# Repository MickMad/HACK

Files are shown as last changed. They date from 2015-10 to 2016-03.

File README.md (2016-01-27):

#HACK
##HackAday Cortex Kit

A Cortex-M0+ development kit with an Atmel SAM R21, a USB device/host port, a regulator, some passives, a programming header, and breakout headers.

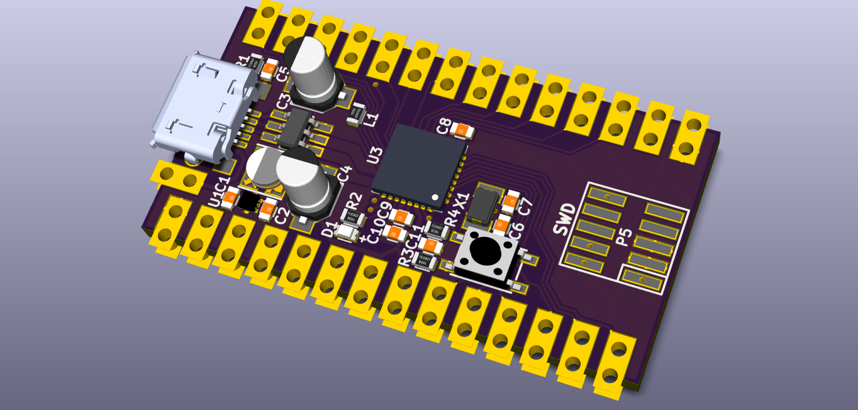
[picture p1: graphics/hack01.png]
HACK top


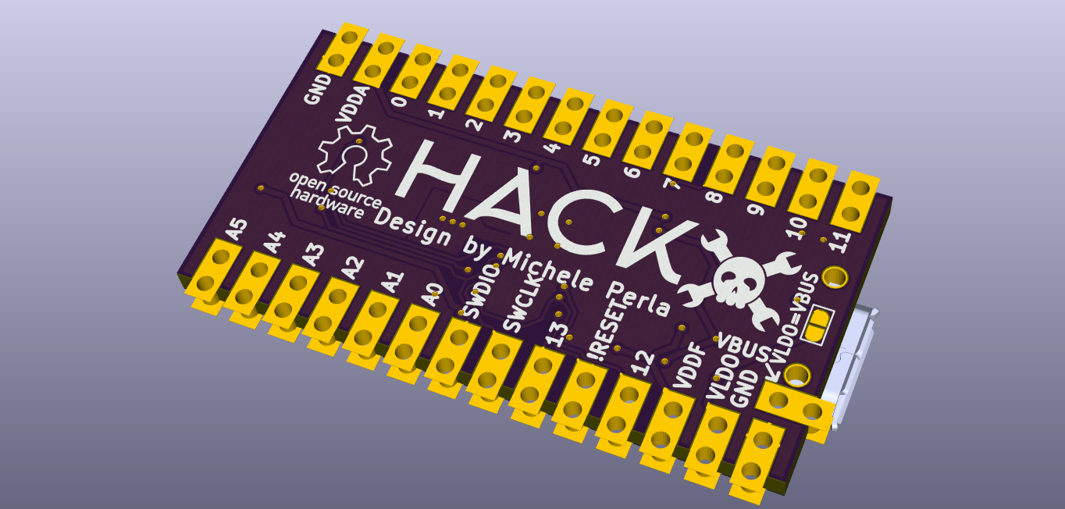
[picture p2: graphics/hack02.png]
HACK bottom


```
Copyright © Michele Perla 2015

This documentation describes Open Hardware and is licensed under the CERN OHL v. 1.2.
You may redistribute and modify this documentation under the terms of the CERN OHL v.1.2. 
(http://ohwr.org/cernohl). This documentation is distributed
WITHOUT ANY EXPRESS OR IMPLIED WARRANTY, INCLUDING OF
MERCHANTABILITY, SATISFACTORY QUALITY AND FITNESS FOR A
PARTICULAR PURPOSE. Please see the CERN OHL v.1.2 for applicable
conditions
```

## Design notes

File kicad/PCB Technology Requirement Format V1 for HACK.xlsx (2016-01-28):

深圳矽递科技有限公司Seeed Technology Inc.
PCB Technology Requirement Format
PCB Name & Version | HACK, rev 1
PCB Material PCB板材： | (Rigid)FR－4
PCB Size PCB大小： | inch | (1.4500) × (0.7500)
PCB Layer PCB层数： | 2
Thickness PCB厚度：
 |  | 1.6mm
Copper Weight铜厚： | 1oz
PCB Colour阻焊颜色： |  | Black黑色
Silkscreen字符颜色： |  | White白色
Pads Finished焊盘喷镀： | (Hasl-lead free)无铅喷锡
Via solder mask阻焊覆盖： |  | solder mask opening过孔开窗
Minimum trace/space (mm)最小线宽 | 0.178mm | Minimum hole size (mm)最小孔径 | 0.508mm
Special requirements特殊工艺： | YES | (Put requirements here)
Comment: | Do not solder Header Pins (add as kit)

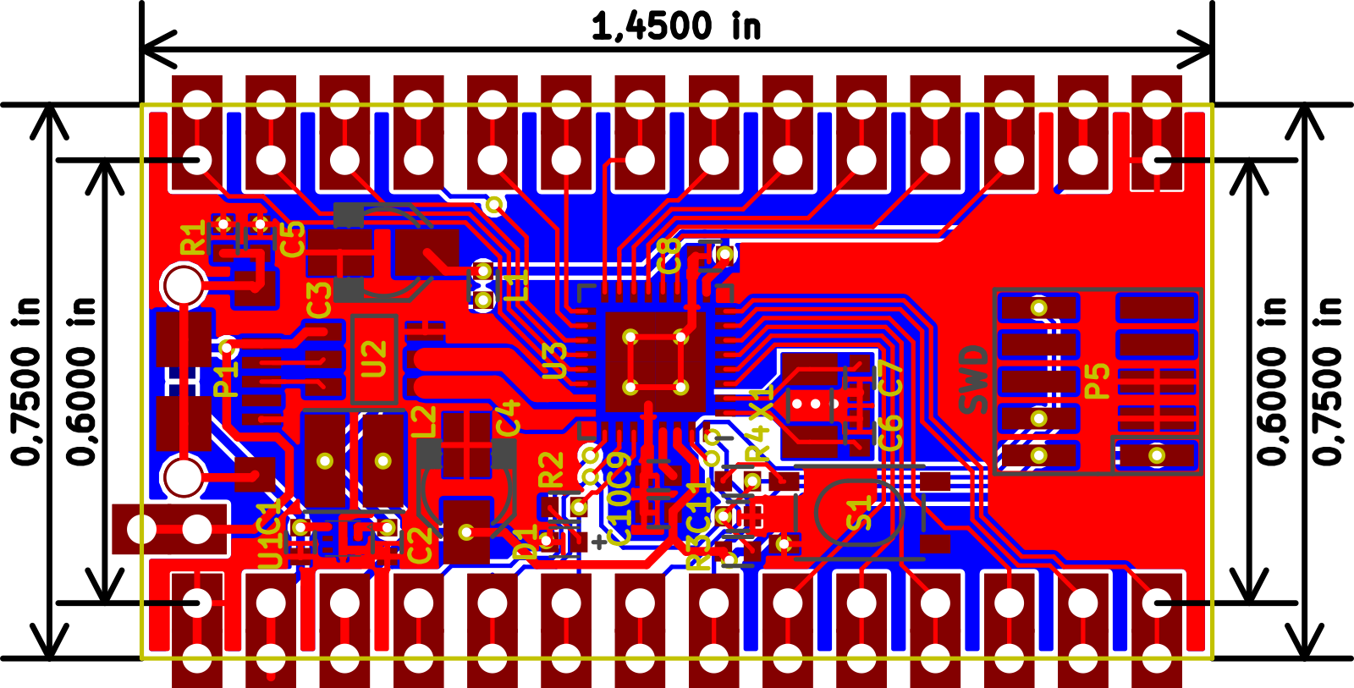
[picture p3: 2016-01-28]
graphics/hack-brd.png

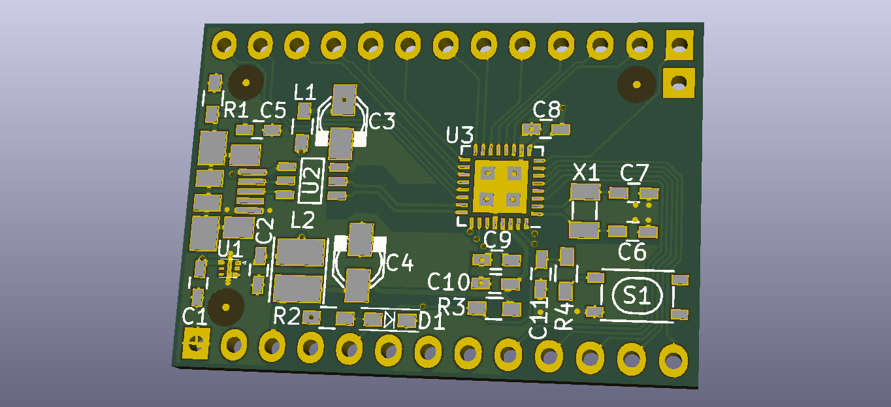
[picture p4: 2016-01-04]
graphics/hack - 3D top.png

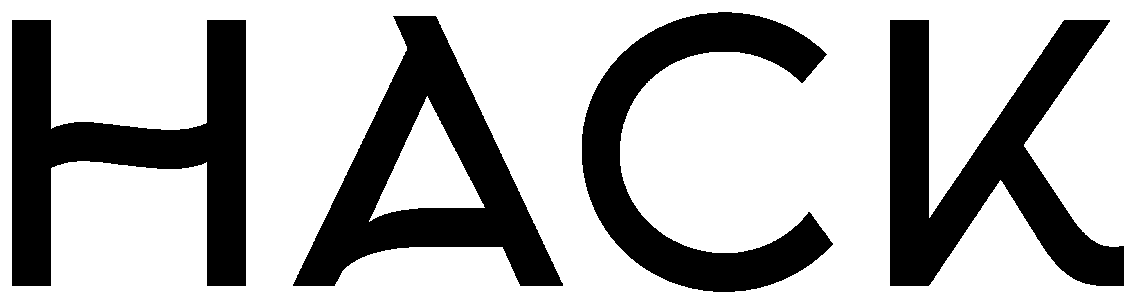
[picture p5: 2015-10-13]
graphics/hack.bmp

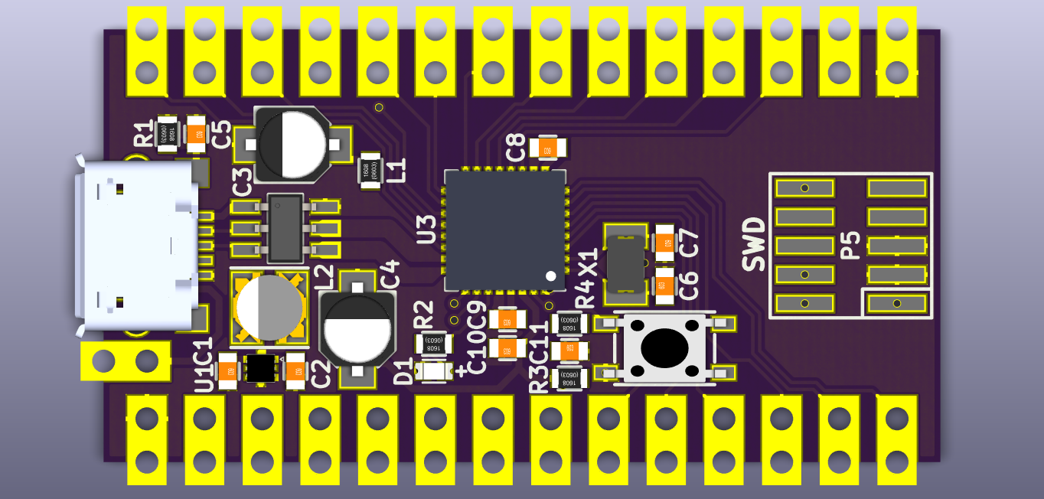
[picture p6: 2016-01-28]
graphics/hack03.png

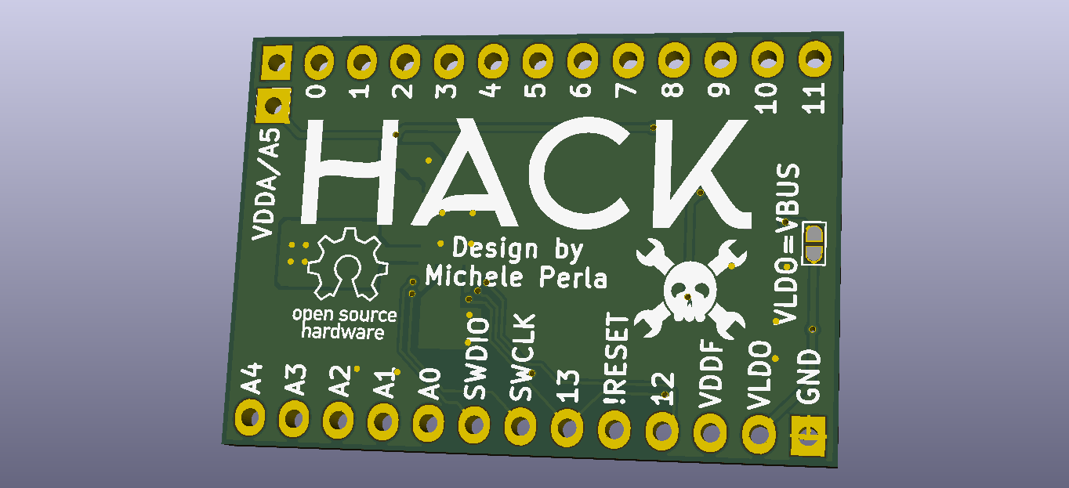
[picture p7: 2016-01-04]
graphics/hack - 3D bottom.png

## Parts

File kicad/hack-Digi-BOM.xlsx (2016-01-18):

 |  |  |  |  |  |  | Board Qty: | 21
 |  |  |  |  |  |  | Total Cost: | $171.97 |  |  |  | $182.13 |  |  |  |  |  | $195.82 |  |  |  |  |  | $137.80
 |  |  |  |  |  |  | Unit Cost: | $8.19
Global Part Info |  |  |  |  |  |  |  |  | Digi-Key |  |  |  |  |  | Mouser |  |  |  |  |  | Newark
Refs | Value | Desc | Footprint | Manf | Manf# | Qty | Unit$ | Ext$ | Avail | Purch | Unit$ | Ext$ | Cat# | Doc | Avail | Purch | Unit$ | Ext$ | Cat# | Doc | Avail | Purch | Unit$ | Ext$ | Cat# | Doc
C3,C4 | 10uF |  | hack-footprints:c_elec_3x5.3 |  | UWX1C100MCL2GB | 42 | $0.13 | $5.63 | 146304 |  | $0.16 | $6.84 | 493-2099-1-ND | Link (http://www.digikey.com/product-detail/en/UWX1C100MCL2GB/493-2099-1-ND/590074) | 22886 |  | $0.13 | $5.63 | 647-UWX1C100MCL2 | Link (http://www.mouser.com/Search/Refine.aspx?Keyword=UWX1C100MCL2GB) | 829 |  | $0.20 | $8.19 | 58R3619 | Link (http://www.newark.com/nichicon/uwx1c100mcl2gb/aluminum-electrolytic-capacitor/dp/58R3619)
D1 | RED |  | hack-footprints:LED_0603_HandSoldering |  | LTST-C190KRKT | 21 | $0.19 | $3.91 | 294147 |  | $0.19 | $3.91 | 160-1436-1-ND | Link (http://www.digikey.com/product-detail/en/LTST-C190KRKT/160-1436-1-ND/386816) | 47288 |  | $0.23 | $4.87 | 859-LTST-C190KRKT | Link (http://www.mouser.com/Search/Refine.aspx?Keyword=LTST-C190KRKT) | 1769 |  | $0.43 | $9.11 | 09J9435 | Link (http://www.newark.com/lumex/sml-lx0603siw-tr/led-red-0-8mm-x-1mm-60mcd-636nm/dp/09J9435)
U2 | STF202 |  | hack-footprints:TSOP-6 |  | STF202-22T1G | 21 | $0.49 | $10.33 | 10793 |  | $0.57 | $11.95 | STF202-22T1GOSCT-ND | Link (http://www.digikey.com/product-detail/en/STF202-22T1G/STF202-22T1GOSCT-ND/720944) | 12154 |  | $0.49 | $10.33 | 863-STF202-22T1G | Link (http://www.mouser.com/Search/Refine.aspx?Keyword=STF202-22T1G) | 7927 |  | $0.66 | $13.86 | 45J2271 | Link (http://www.newark.com/on-semiconductor/stf202-22t1g/rc-n-w-filter-22-ohm-68pf-tsop/dp/45J2271)
C5 | 4.7nF |  | hack-footprints:C_0603_HandSoldering |  | CC0603KRX7R9BB472 | 21 | $0.02 | $0.40 | 45511 |  | $0.03 | $0.55 | 311-1083-1-ND | Link (http://www.digikey.com/product-detail/en/CC0603KRX7R9BB472/311-1083-1-ND/302993) | 48553 |  | $0.02 | $0.40 | 603-C0603KRX7R9BB472 | Link (http://www.mouser.com/Search/Refine.aspx?Keyword=CC0603KRX7R9BB472) | 2940 |  | $0.05 | $0.97 | 68R4808 | Link (http://www.newark.com/yageo/cc0603krx7r9bb472/ceramic-capacitor-4700pf-50v-x7r/dp/68R4808)
L2 | 10uH |  | hack-footprints:ELLVFG |  | ELL-VFG100MC | 21 | $0.21 | $4.45 | 526 |  | $0.51 | $10.71 | PCD2293CT-ND | Link (http://www.digikey.com/product-detail/en/ELL-VFG100MC/PCD2293CT-ND/1938502) | 1767 |  | $0.47 | $9.91 | 667-ELL-VFG100MC | Link (http://www.mouser.com/Search/Refine.aspx?Keyword=ELL-VFG100MC) | 0 |  | $0.21 | $4.45 | 15R1033 | Link (http://www.newark.com/webapp/wcs/stores/servlet/Search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)
U3 | ATSAMD21E |  | hack-footprints:QFN-32-1EP_5x5mm_Pitch0.5mm |  | ATSAMD21E18A-MU | 21 | $3.04 | $63.84 | 907 |  | $4.49 | $94.35 | ATSAMD21E18A-MU-ND | Link (http://www.digikey.com/product-detail/en/ATSAMD21E18A-MU/ATSAMD21E18A-MU-ND/4935887) | 328 |  | $4.43 | $93.03 | 556-ATSAMD21E18A-MU | Link (http://www.mouser.com/ProductDetail/Atmel/ATSAMD21E18A-MU/) | 0 |  | $3.04 | $63.84 | 45X9914 | Link (http://www.newark.com/atmel/atsamd21e18a-mu/cortex-m0-64kb-flash-8kb-sram/dp/45X9914)
L1 | BLM18EG221 |  | hack-footprints:L_0603_HandSoldering |  | BLM18EG221SN1D | 21 | $0.10 | $2.12 | 309192 |  | $0.17 | $3.67 | 490-3992-1-ND | Link (http://www.digikey.com/product-detail/en/BLM18EG221SN1D/490-3992-1-ND/1016252) | 80667 |  | $0.12 | $2.60 | 81-BLM18EG221SN1D | Link (http://www.mouser.com/Search/Refine.aspx?Keyword=BLM18EG221SN1D) | 13079 |  | $0.10 | $2.12 | 73M9090 | Link (http://www.newark.com/murata/blm18eg221sn1d/ferrite-bead-0-05ohm-2a-0603/dp/73M9090)
R3 | 10k |  | hack-footprints:R_0603_HandSoldering |  | RC0603FR-0710KL | 21 | $0.01 | $0.21 | 10065467 |  | $0.01 | $0.29 | 311-10.0KHRCT-ND | Link (http://www.digikey.com/product-detail/en/RC0603FR-0710KL/311-10.0KHRCT-ND/729827) | 2016779 |  | $0.01 | $0.21 | 603-RC0603FR-0710KL | Link (http://www.mouser.com/Search/Refine.aspx?Keyword=RC0603FR-0710KL) | 4809 |  | $0.01 | $0.32 | 68R0049 | Link (http://www.newark.com/yageo/rc0603fr-0710kl/res-thick-film-10k-1-0-1w-0603/dp/68R0049)
S1 | RST |  | hack-footprints:SPST-PTS_810 |  | PTS810 SJM 250 SMTR LFS | 21 | $0.27 | $5.63 | 39749 |  | $0.27 | $5.63 | CKN10502CT-ND | Link (http://www.digikey.com/product-detail/en/PTS810%20SJM%20250%20SMTR%20LFS/CKN10502CT-ND/4176673) | 5616 |  | $0.28 | $5.86 | 611-PTS810SJM250SMTR | Link (http://www.mouser.com/ProductDetail/CK-Components/PTS810-SJM-250-SMTR-LFS/)
P1 | USB_micro |  | hack-footprints:ST-USB-001G |  | 10118193-0001LF | 21 | $0.31 | $6.53 | 147639 |  | $0.43 | $9.09 | 609-4616-1-ND | Link (http://www.digikey.com/product-detail/en/10118193-0001LF/609-4616-1-ND/2785380) | 20536 |  | $0.32 | $6.76 | 649-10118193-0001LF | Link (http://www.mouser.com/Search/Refine.aspx?Keyword=10118193-0001LF) | 8721 |  | $0.31 | $6.53 | 67T2259 | Link (http://www.newark.com/webapp/wcs/stores/servlet/Search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)
C1,C2 | 2.2uF |  | hack-footprints:C_0603_HandSoldering |  | CC0603MRX5R5BB225 | 42 | $0.05 | $2.18 | 5474 |  | $0.05 | $2.23 | 311-1814-1-ND | Link (http://www.digikey.com/product-detail/en/CC0603MRX5R5BB225/311-1814-1-ND/5195716) | 3965 |  | $0.05 | $2.18 | 603-CC603MRX5R5BB225 | Link (http://www.mouser.com/Search/Refine.aspx?Keyword=CC0603MRX5R5BB225) | 3272 |  | $0.12 | $4.87 | 06R5243 | Link (http://www.newark.com/multicomp/mc0603x225m6r3ct/ceramic-capacitor-2-2uf-6-3v-x5r/dp/06R5243)
U1 | MIC5528 |  | hack-footprints:DFN-6-1EP_1.2x1.2mm_Pitch0.4mm |  | MIC5528-3.3YMT-TR | 21 | $0.19 | $3.93 | 4970 |  | $0.19 | $3.99 | 576-4766-1-ND | Link (http://www.digikey.com/product-detail/en/MIC5528-3.3YMT-TR/576-4766-1-ND/4864030) | 4794 |  | $0.19 | $3.93 | 998-MIC5528-3.3YMTTR | Link (http://www.mouser.com/Search/Refine.aspx?Keyword=MIC5528-3.3YMT-TR)
C8-C11 | 100nF |  | hack-footprints:C_0603_HandSoldering |  | CC0603KRX7R9BB104 | 84 | $0.02 | $1.68 | 1594945 |  | $0.02 | $1.71 | 311-1344-1-ND | Link (http://www.digikey.com/product-detail/en/CC0603KRX7R9BB104/311-1344-1-ND/2103128) | 589899 |  | $0.02 | $1.68 | 603-CC603KRX7R9BB104 | Link (http://www.mouser.com/Search/Refine.aspx?Keyword=CC0603KRX7R9BB104) | 2488 |  | $0.03 | $2.18 | 68R4788 | Link (http://www.newark.com/yageo/cc0603krx7r9bb104/ceramic-capacitor-0-1uf-50v-x7r/dp/68R4788)
R1 | 1M |  | hack-footprints:R_0603_HandSoldering |  | RC0603FR-071ML | 21 | $0.01 | $0.21 | 1335355 |  | $0.01 | $0.29 | 311-1.00MHRCT-ND | Link (http://www.digikey.com/product-detail/en/RC0603FR-071ML/311-1.00MHRCT-ND/729791) | 150640 |  | $0.01 | $0.21 | 603-RC0603FR-071ML | Link (http://www.mouser.com/Search/Refine.aspx?Keyword=RC0603FR-071ML) | 4058 |  | $0.01 | $0.32 | 68R0047 | Link (http://www.newark.com/yageo/rc0603fr-071ml/res-thick-film-1m-1-0-1w-0603/dp/68R0047)
P2,P3 | CONN_01X13 |  | hack-footprints:Pin_Castellated_1x13 |  | PREC014SACN-RC | 42 | $0.31 | $13.06 | 0 |  | $0.31 | $13.06 | S1032EC-14-ND | Link (http://www.digikey.com/scripts/DkSearch/dksus.dll?WT.z_header=search_go&lang=en)
R2,R4 | 330 |  | hack-footprints:R_0603_HandSoldering |  | RC0603FR-07330RL | 42 | $0.002 | $0.08 | 547143 |  | $0.01 | $0.42 | 311-330HRCT-ND | Link (http://www.digikey.com/product-detail/en/RC0603FR-07330RL/311-330HRCT-ND/730109) | 132614 |  | $0.01 | $0.42 | 603-RC0603FR-07330RL | Link (http://www.mouser.com/Search/Refine.aspx?Keyword=RC0603FR-07330RL) | 2000 |  | $0.002 | $0.08 | 75X0150 | Link (http://www.newark.com/yageo-phycomp/rc0603fr-07330rl/surface-mount-chip-resistor-thick/dp/75X0150)
X1 | ABS07 |  | hack-footprints:xtal_3.2x1.5mm |  | ABS07-32.768KHZ-7-T | 21 | $0.57 | $12.01 | 18822 |  | $0.59 | $12.43 | 535-9543-1-ND | Link (http://www.digikey.com/product-detail/en/ABS07-32.768KHZ-7-T/535-9543-1-ND/1237010) | 25120 |  | $0.57 | $12.01 | 815-ABS07-32.768K7T | Link (http://www.mouser.com/Search/Refine.aspx?Keyword=ABS07-32.768KHZ-7-T) | 7891 |  | $0.92 | $19.32 | 14N8750 | Link (http://www.newark.com/abracon/abs07-32-768khz-7-t/crystal-32-768khz-7pf-3-2-x-1/dp/14N8750)
C6,C7 | 10pF |  | hack-footprints:C_0603_HandSoldering |  | CC0603JRNPO9BN100 | 42 | $0.02 | $0.99 | 33300 |  | $0.02 | $0.99 | 311-1058-1-ND | Link (http://www.digikey.com/product-detail/en/CC0603JRNPO9BN100/311-1058-1-ND/302968) | 22668 |  | $0.02 | $1.01 | 603-C0603JRNPO9BN100 | Link (http://www.mouser.com/Search/Refine.aspx?Keyword=CC0603JRNPO9BN100) | 800 |  | $0.04 | $1.64 | 68R4712 | Link (http://www.newark.com/yageo/cc0603jrnpo9bn100/ceramic-capacitor-10pf-50v-c0g/dp/68R4712)

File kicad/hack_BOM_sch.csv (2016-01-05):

Reference | Value | Footprint | Datasheet | manf#
U3 | ATSAMD21E | hack:QFN-32-1EP_5x5mm_Pitch0.5mm
U2 | STF202 | hack:TSOP-6
P1 | USB_micro | hack:47346-0001
R1 | 1M | hack:R_0603_HandSoldering
C5 | 4.5nF | hack:C_0603_HandSoldering
C6 | 10pF | hack:C_0603_HandSoldering
C7 | 10pF | hack:C_0603_HandSoldering
C3 | 10uF | hack:c_elec_3x5.3
C8 | 100nF | hack:C_0603_HandSoldering
C9 | 100nF | hack:C_0603_HandSoldering
C10 | 100nF | hack:C_0603_HandSoldering
L2 | 10uH | hack:ELLVFG
L1 | BLM18EG221 | hack:L_0603_HandSoldering
C4 | 10uF | hack:c_elec_3x5.3
P2 | CONN_01X13 | hack-footprints:Pin_Castellated_1x13
P3 | CONN_01X13 | hack-footprints:Pin_Castellated_1x13
D1 | BLUE | hack:LED_0603_HandSoldering
R2 | 68 | hack:R_0603_HandSoldering
R4 | 330 | hack:R_0603_HandSoldering
C11 | 100nF | hack:C_0603_HandSoldering
S1 | RST | hack-footprints:SPST-PTS_810
R3 | 10k | hack:R_0603_HandSoldering
U1 | MIC5528 | hack:DFN-6-1EP_1.2x1.2mm_Pitch0.4mm
C1 | 2.2uF | hack:C_0603_HandSoldering
C2 | 2.2uF | hack:C_0603_HandSoldering
JP1 | Jumper_NO_Small | hack:SMD_Jumper
P4 | CONN_01X01 | hack-footprints:Pin_Castellated_1x01
FID1 | FIDUCIAL | hack:FIDUCIAL
FID2 | FIDUCIAL | hack:FIDUCIAL
FID3 | FIDUCIAL | hack:FIDUCIAL
LOGO2 | HACKADAY | hack:HACKADAY-LOGO |  | mfr_pn
LOGO1 | OSHW | hack:OSHW-LOGO |  | mfr_pn
LOGO3 | HACK |  |  | Value
X1 | ABS07

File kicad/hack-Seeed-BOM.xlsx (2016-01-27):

Refs | Value | Manufacturer Part No | Qty | Unit$ | order from | NOTES
C1,C2 | 2.2uF | CC0603MRX5R5BB225 | 2 | 0.051 | Digikey
C3,C4 | 10uF | UWX1C100MCL2GB | 2 | 0.134 | Digikey
C5 | 4.7nF | 302010144 | 1 | 0.010 | Seeed
C6,C7 | 10pF | 302010097 | 2 | 0.010 | Seeed
C8-C11 | 100nF | 302010138 | 4 | 0.020 | Seeed
D1 | RED | 304090042 | 1 | 0.030 | Seeed
L1 | BLM18EG221 | BLM18EG221SN1D | 1 | 0.103 | Digikey
L2 | 10uH | ELL-VFG100MC | 1 | 0.212 | Digikey
P1 | USB_micro | 10118193-0001LF | 1 | 0.300 | Digikey
P2,P3 | CONN_01X14 | 320020128 | 1 | 0.080 | Seeed | PLACEHOLDER, end user will cut the header (40 positions) and solder it
P5 | CONN_SWD | 320020119 | 1 | 0.2036 | Seeed
R1 | 1M | 301010151 | 1 | 0.010 | Seeed
R2,R4 | 330 | 301010300 | 2 | 0.010 | Seeed
R3 | 10k | 301010299 | 1 | 0.010 | Seeed
S1 | RST | 311020045 | 1 | 0.204 | Seeed
U1 | MIC5528 | MIC5528-3.3YMT-TR | 1 | 0.187 | Digikey
U2 | STF202 | STF202-22T1G | 1 | 0.492 | Digikey
U3 | ATSAMD21E | ATSAMD21E18A-MU | 1 | 3.040 | Digikey
X1 | ABS07 | 306010055 | 1 | 0.350 | Seeed

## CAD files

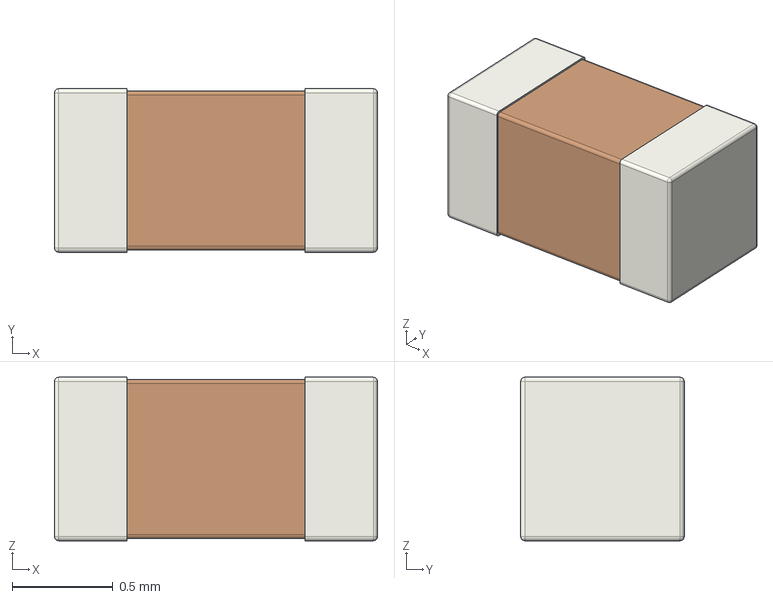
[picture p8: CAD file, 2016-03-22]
kicad/3d_models/Cap_SMD_0603.step
1.60 x 0.81 x 0.81 mm

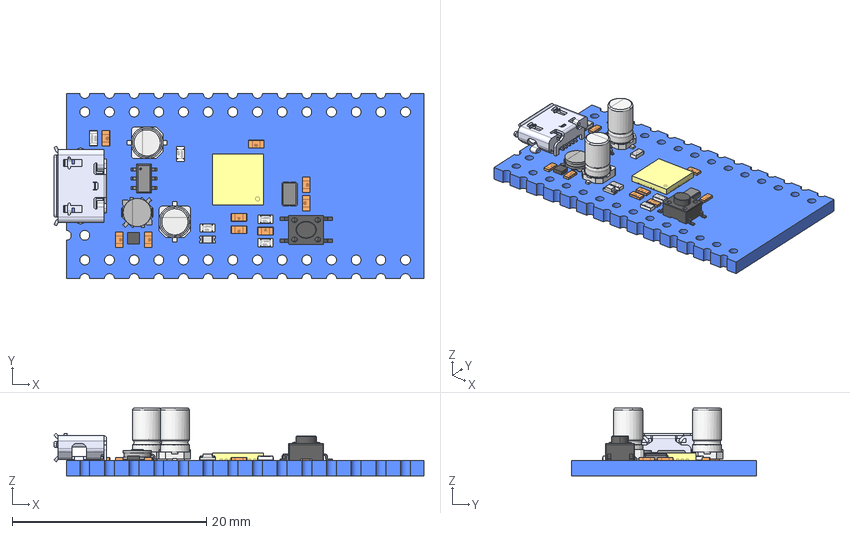
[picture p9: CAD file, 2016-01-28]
kicad/fabricate/hack.FCStd
38.1 x 19.1 x 7.00 mm
Board_outline
User_Library-MicroUSB-B_Molex_105017-0001_
Clone_of_User_Library-DFN-6-1_
Clone_of_Clone_of_Fusion_
Clone_of_User_Library-445-CRYTAL-SMD_
User Library-TSOP-6_
Clone_of_c_el_B_D40_L54_
Clone_of_c_el_B_D40_L54_001
Clone_of_Fusion003_
User Library-RESC1608X05N_
User Library-RESC1608X05N_001
User Library-RESC1608X05N_002
User Library-RESC1608X05N_003
SW3dPS-0603_SMD_Capacitor_
SW3dPS-0603_SMD_Capacitor_001
SW3dPS-0603_SMD_Capacitor_002
SW3dPS-0603_SMD_Capacitor_003
SW3dPS-0603_SMD_Capacitor_004
SW3dPS-0603_SMD_Capacitor_005
SW3dPS-0603_SMD_Capacitor_006
SW3dPS-0603_SMD_Capacitor_007
SW3dPS-0603_SMD_Capacitor_008
User Library-RESC1608X05N_004

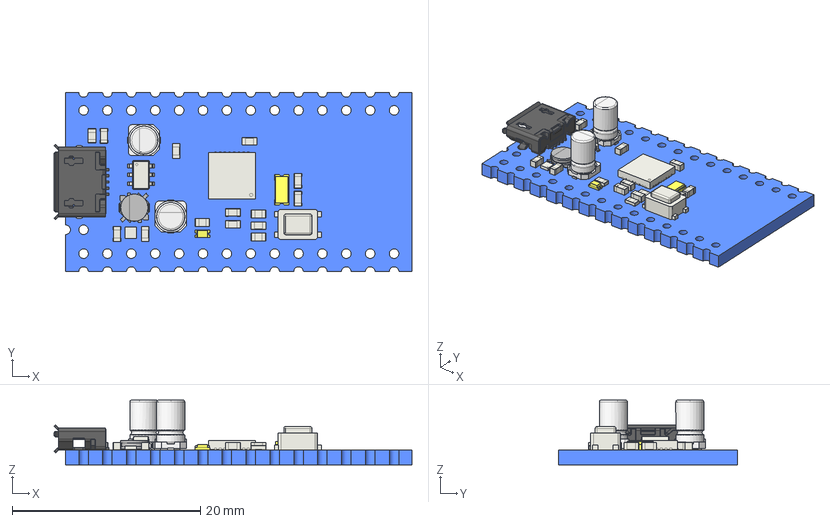
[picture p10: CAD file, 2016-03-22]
kicad/hack.FCStd
38.1 x 19.1 x 6.90 mm
Pcb
10118193-0001LF_
dfn6_1_2x1_2_p040_
SPST_PTS_810_
xtal-abs07_
sot23_6_18x29_p095_
c_el_A_D30_L53_
c_el_A_D30_L53_001
qfn32_500x500_p05_
r_0603_
r_0603_001
r_0603_002
r_0603_003
c_0603_
c_0603_001
c_0603_002
c_0603_003
c_0603_004
c_0603_005
c_0603_006
c_0603_007
c_0603_008
led_0603_
Ind_ell_vfg_
L_0603_

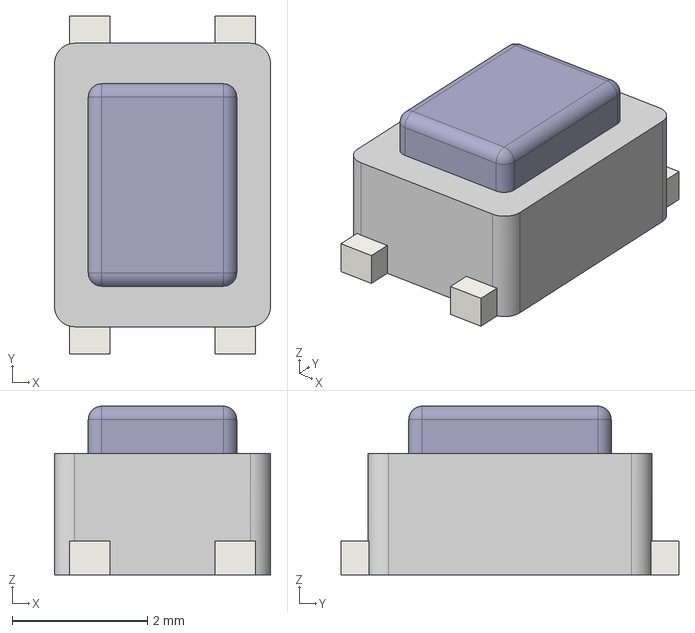
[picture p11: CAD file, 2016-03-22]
kicad/3d_models/SPST_PTS_810.step
3.20 x 5.00 x 2.50 mm

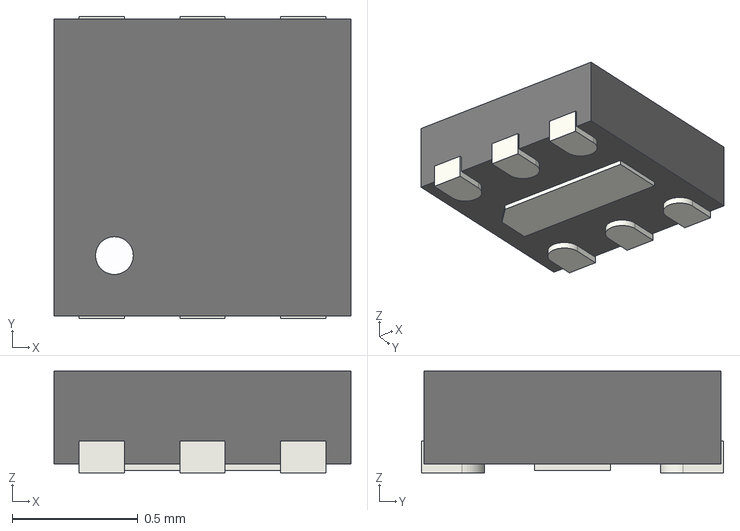
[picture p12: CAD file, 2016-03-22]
kicad/3d_models/LDO_DFN6.step
1.18 x 1.20 x 0.405 mm

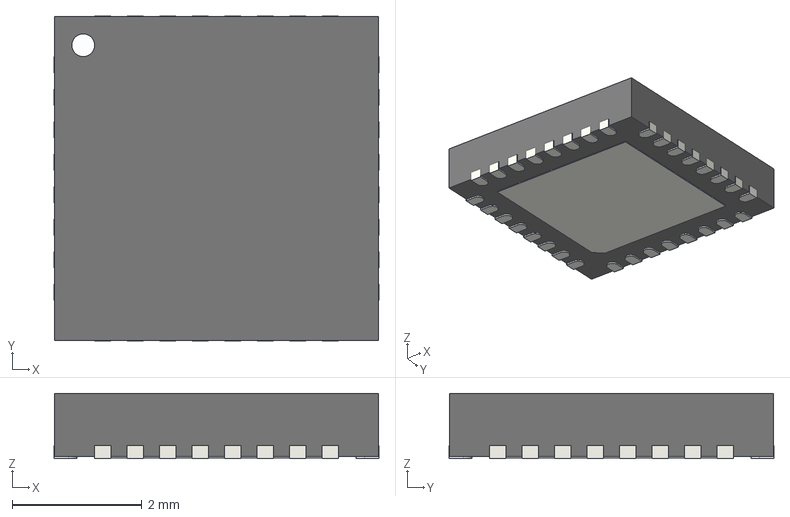
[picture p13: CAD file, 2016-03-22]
kicad/3d_models/QFN-32.step
5.00 x 5.00 x 1.00 mm

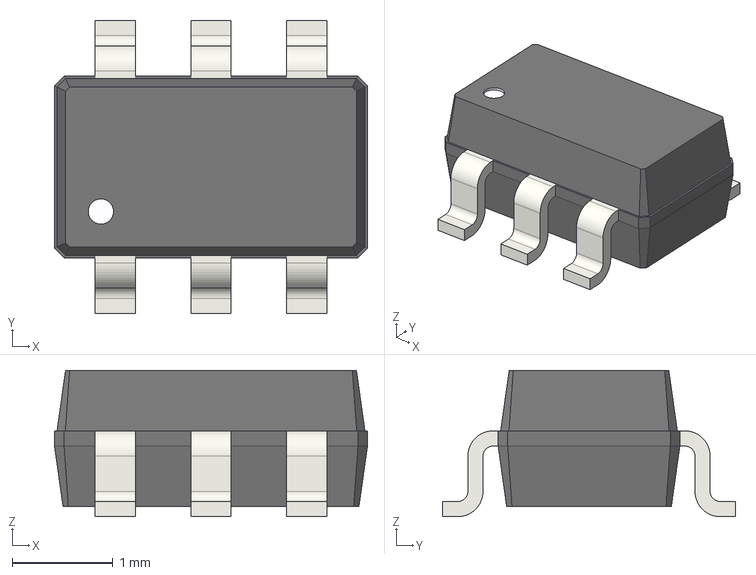
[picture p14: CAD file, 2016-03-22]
kicad/3d_models/TSOP-6.step
3.10 x 2.90 x 1.45 mm

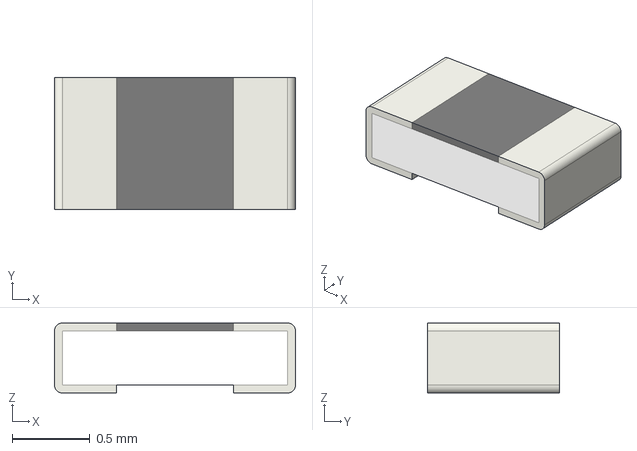
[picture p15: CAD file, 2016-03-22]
kicad/3d_models/RES_SMD_0603.step
1.55 x 0.85 x 0.45 mm

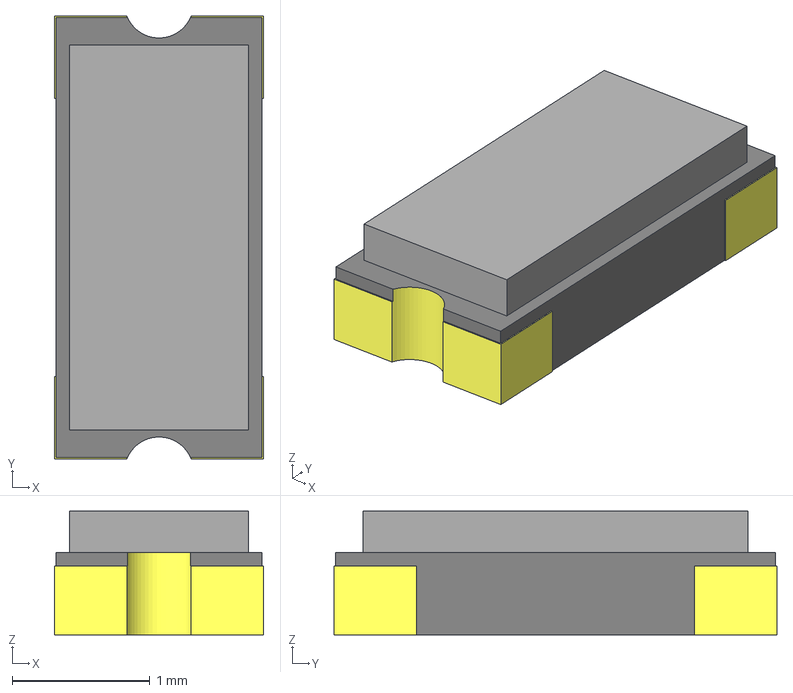
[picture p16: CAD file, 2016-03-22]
kicad/3d_models/Xtal_SMD_ABS07.step
1.52 x 3.22 x 0.9 mm

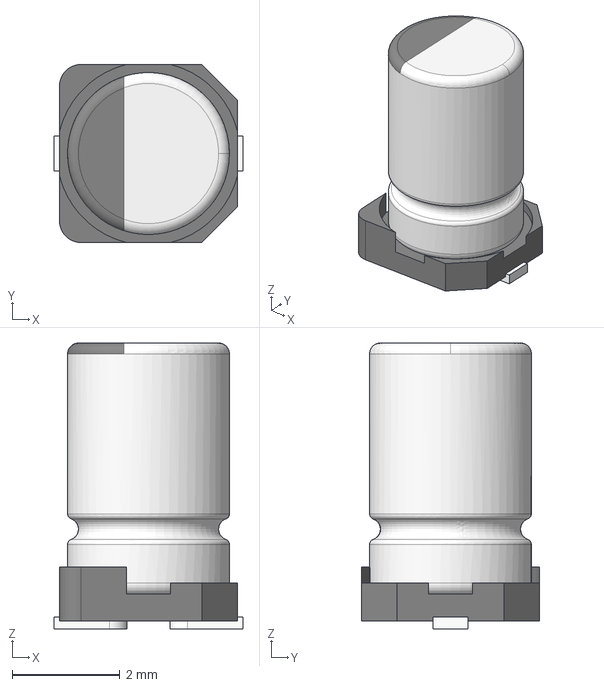
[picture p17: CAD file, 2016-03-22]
kicad/3d_models/Cap_SMD_el_3x5.step
3.50 x 3.30 x 5.30 mm

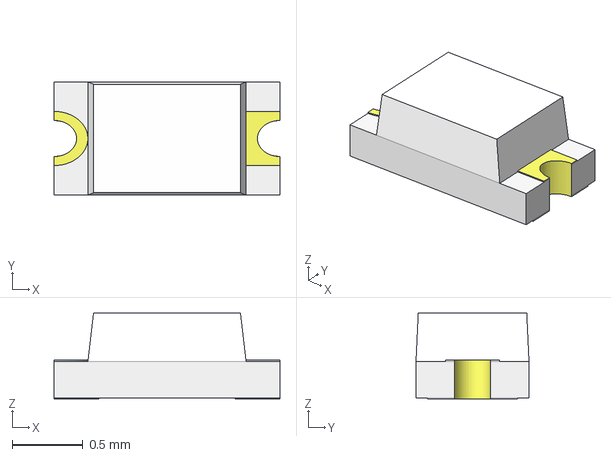
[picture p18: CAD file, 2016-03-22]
kicad/3d_models/LED_SMD_0603.step
1.60 x 0.8 x 0.609 mm

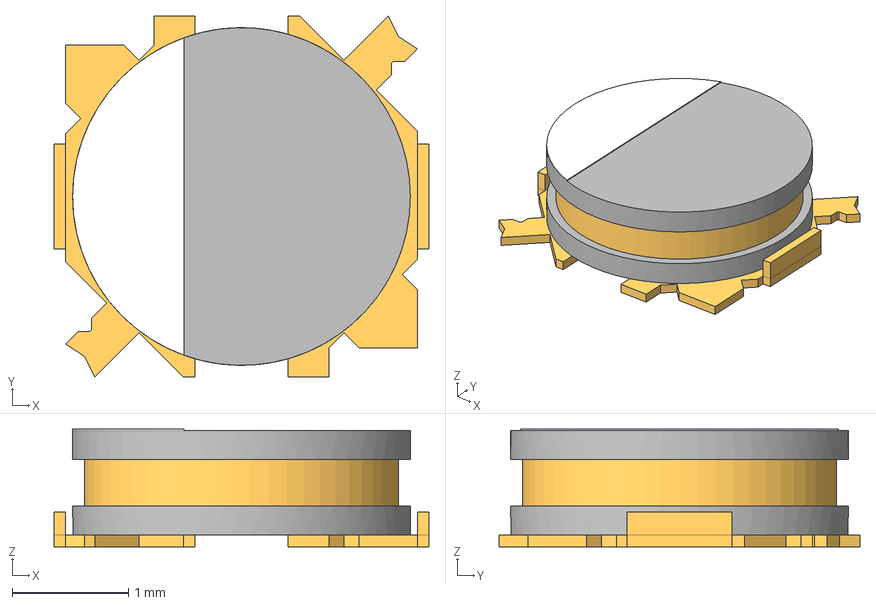
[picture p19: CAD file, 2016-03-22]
kicad/3d_models/Ind_ell_vfg.step
3.22 x 3.10 x 1.01 mm

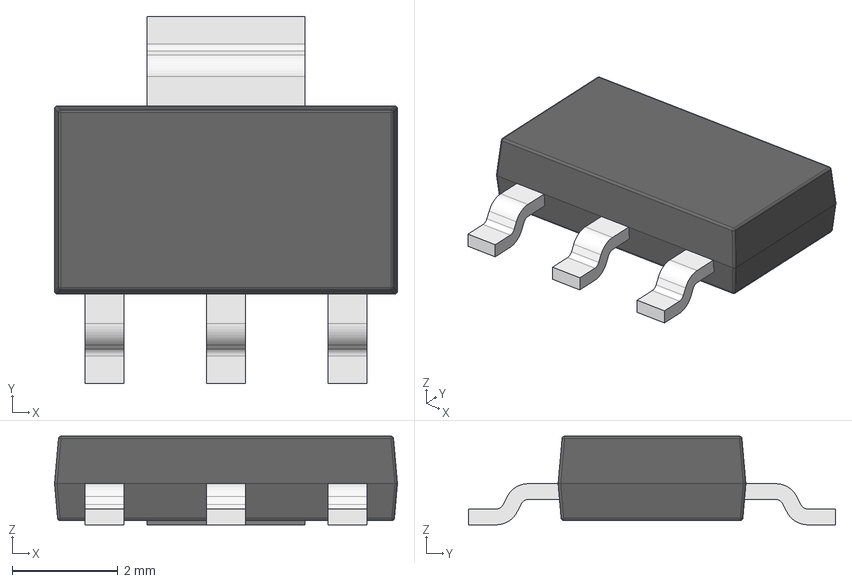
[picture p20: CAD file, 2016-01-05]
kicad/3d_models/SOT-223.step
6.50 x 6.96 x 1.68 mm

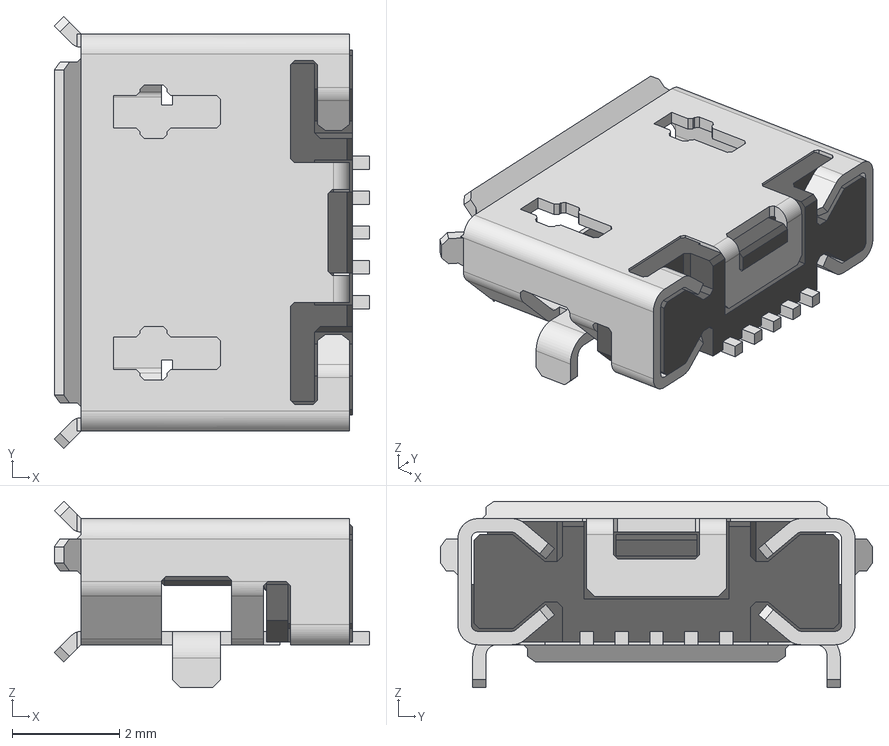
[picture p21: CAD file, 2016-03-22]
kicad/3d_models/10118193-0001LF.step
5.88 x 8.05 x 3.47 mm

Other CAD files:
kicad/3d_models/L_0603.step
kicad/3d_models/Ind_ell_vfg.fcstd

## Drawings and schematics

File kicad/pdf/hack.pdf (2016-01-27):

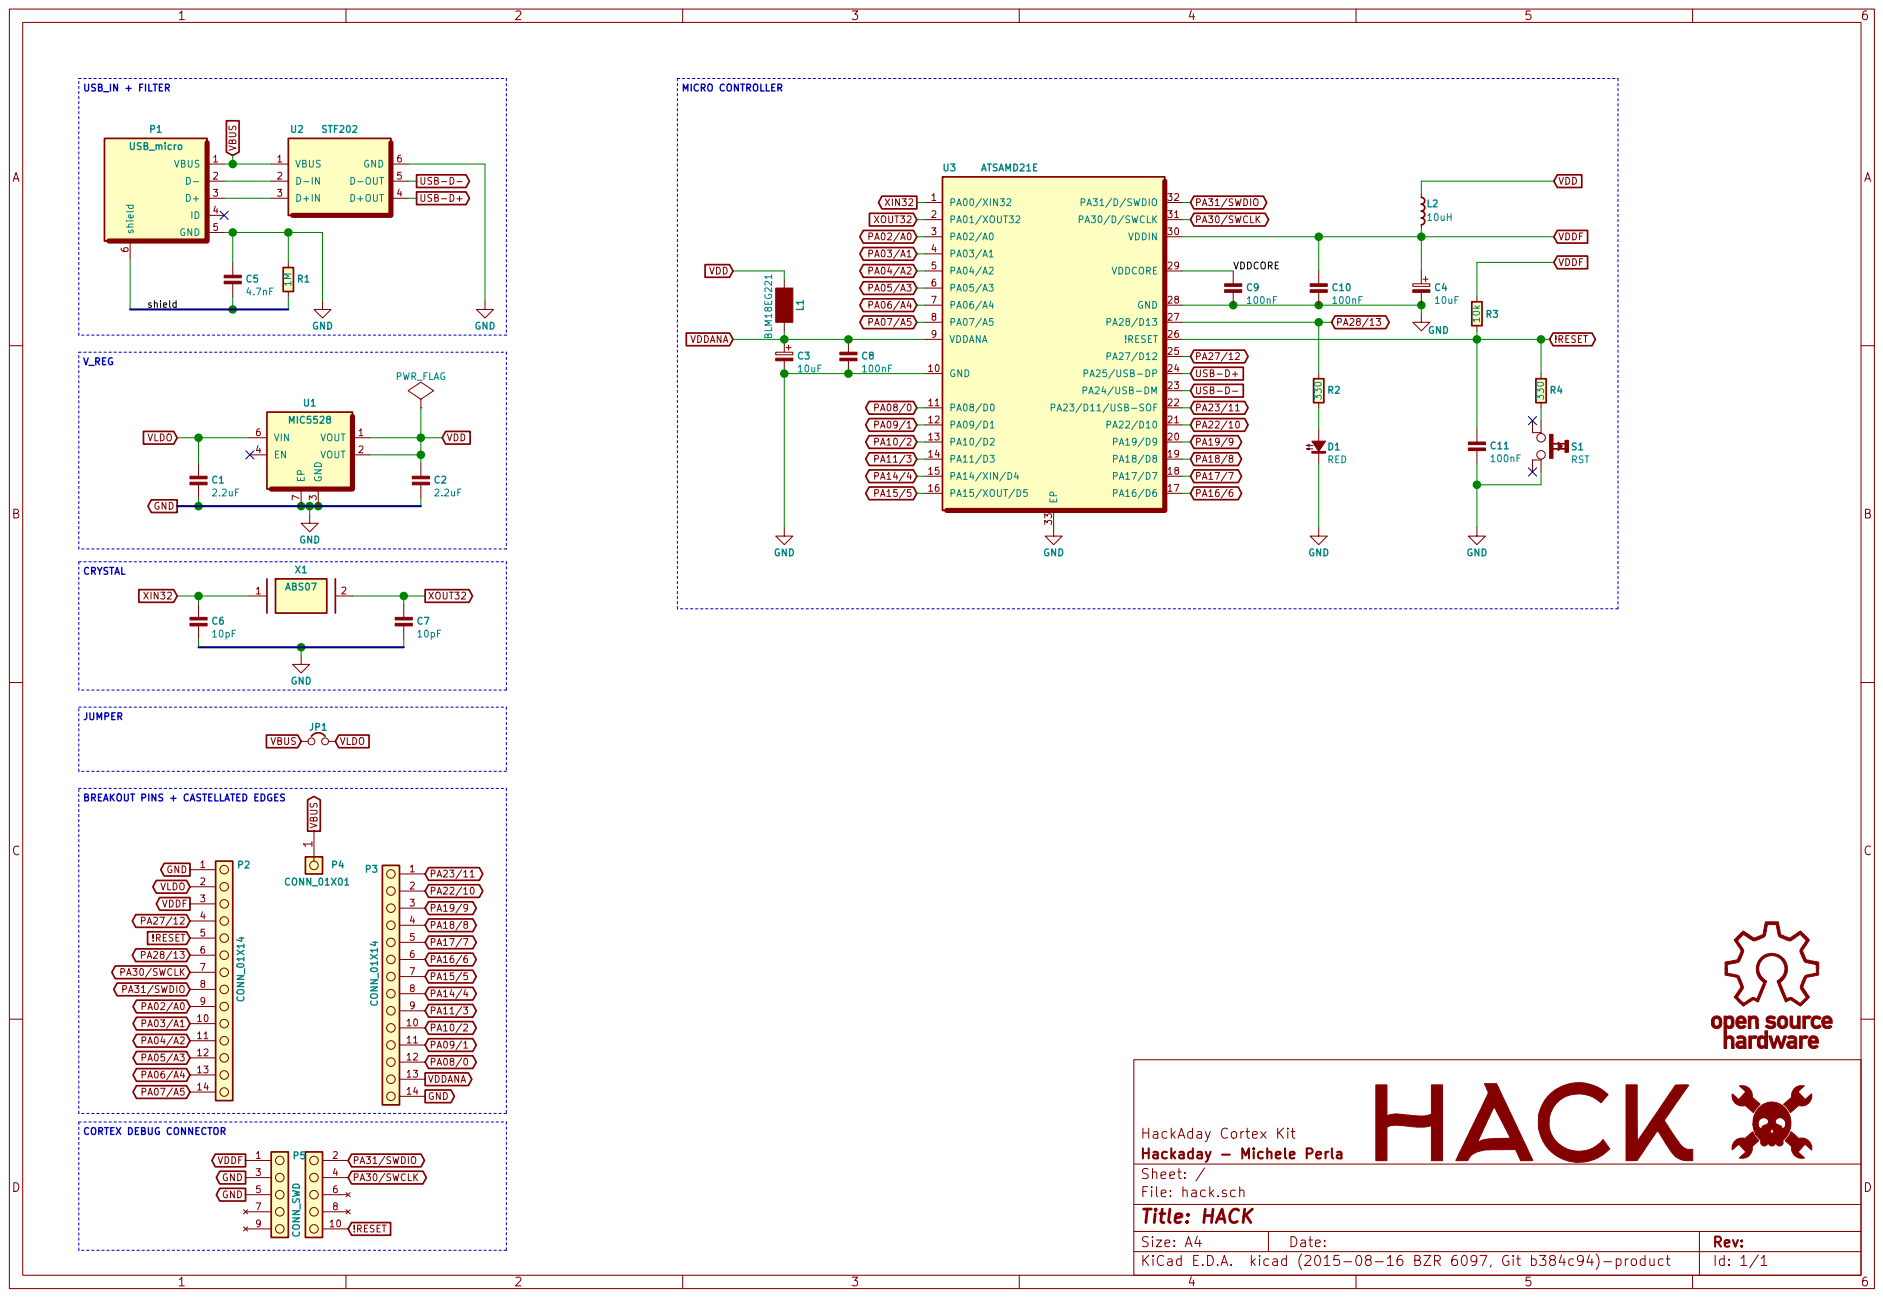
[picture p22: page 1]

6 P1 USB_micro VBUS 1 D-IN 2 D+IN 3 D+OUT 4 D-OUT 5 GND 6 U2 STF202 VOUT 1 VOUT 2 GND

BREAKOUT PINS + CASTELLATED EDGES
GND
VLDO

HackAday Cortex Kit
File: hack.sch Sheet: / Hackaday - Michele Perla

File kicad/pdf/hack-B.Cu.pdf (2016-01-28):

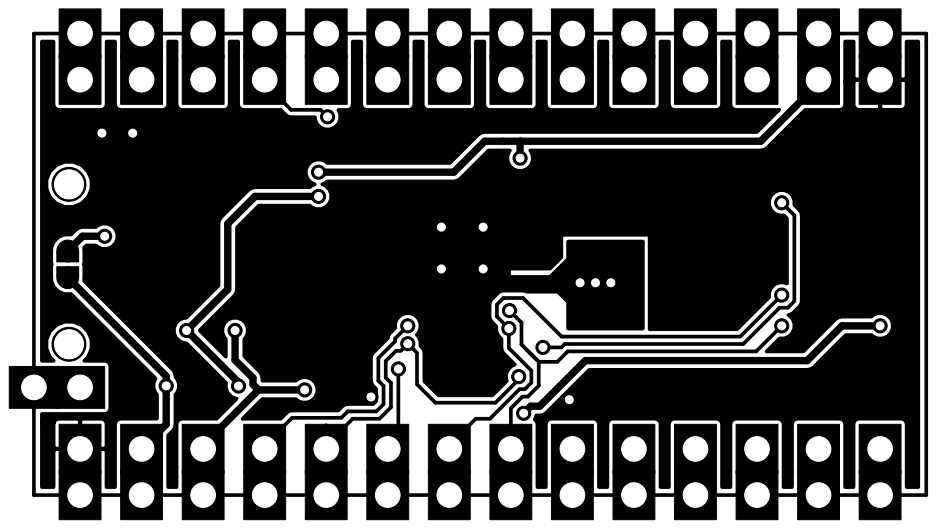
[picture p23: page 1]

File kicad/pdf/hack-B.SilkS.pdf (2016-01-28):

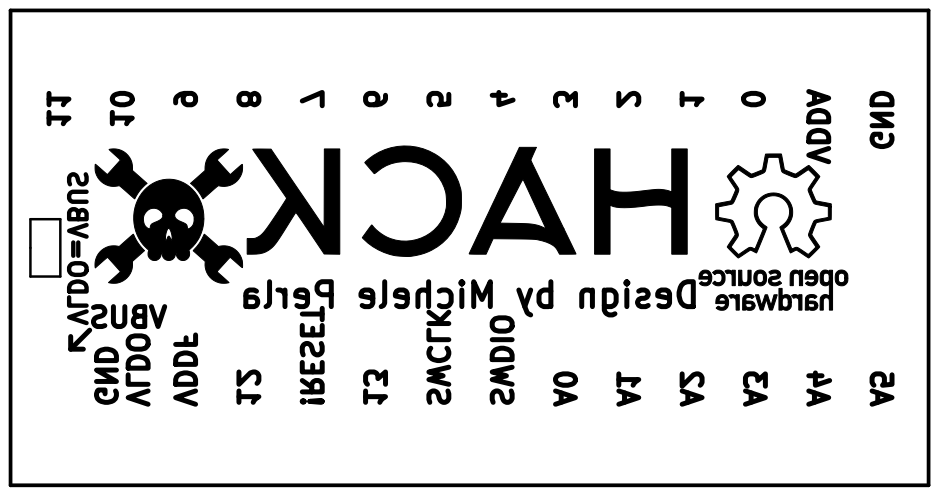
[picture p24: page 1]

11110 VLDO VDDF 12!RESET 13SWCLK SWDIO A0 A1 A2 A3 A4 VBUS Design by Michele Perla

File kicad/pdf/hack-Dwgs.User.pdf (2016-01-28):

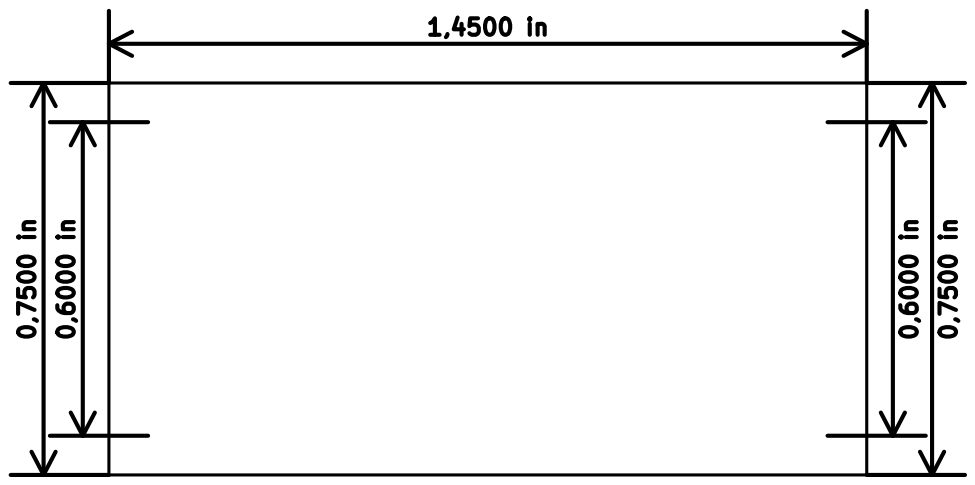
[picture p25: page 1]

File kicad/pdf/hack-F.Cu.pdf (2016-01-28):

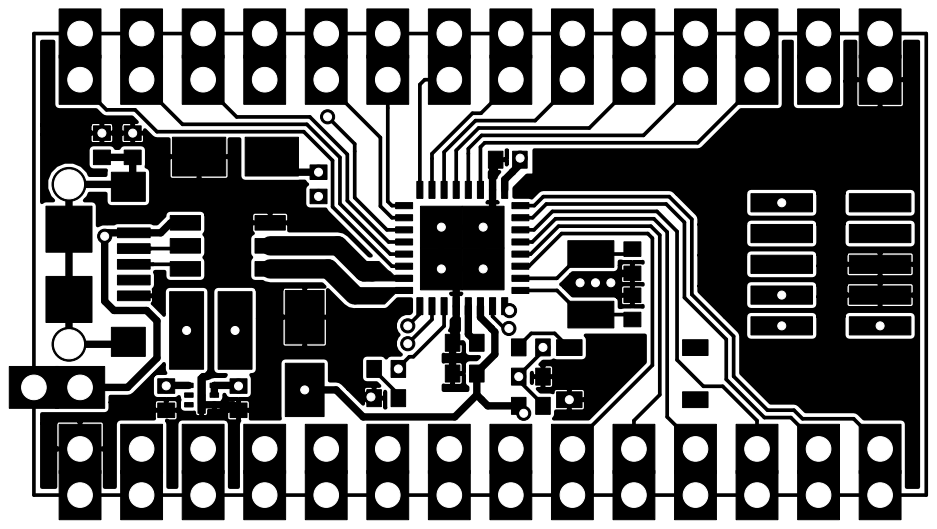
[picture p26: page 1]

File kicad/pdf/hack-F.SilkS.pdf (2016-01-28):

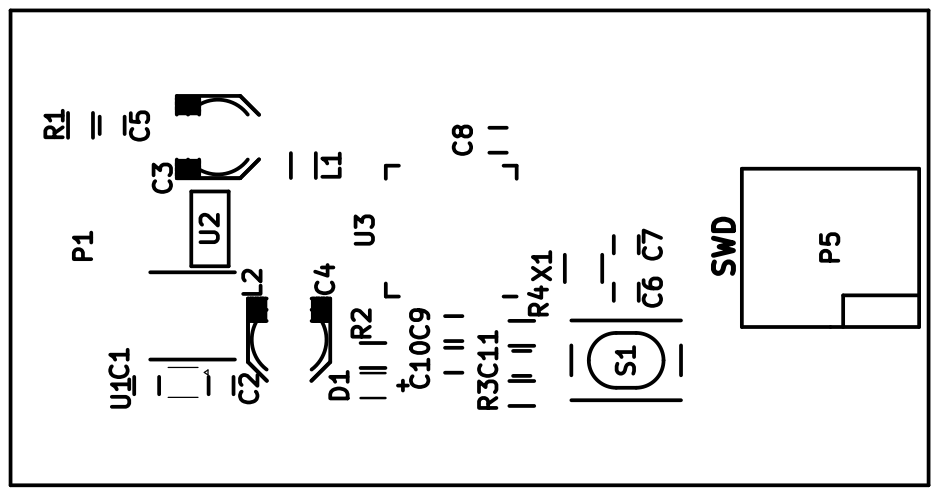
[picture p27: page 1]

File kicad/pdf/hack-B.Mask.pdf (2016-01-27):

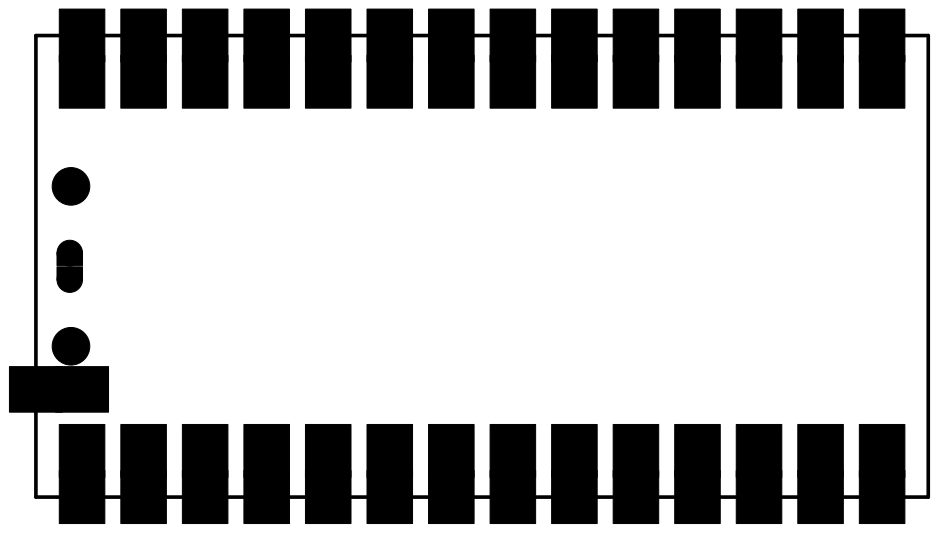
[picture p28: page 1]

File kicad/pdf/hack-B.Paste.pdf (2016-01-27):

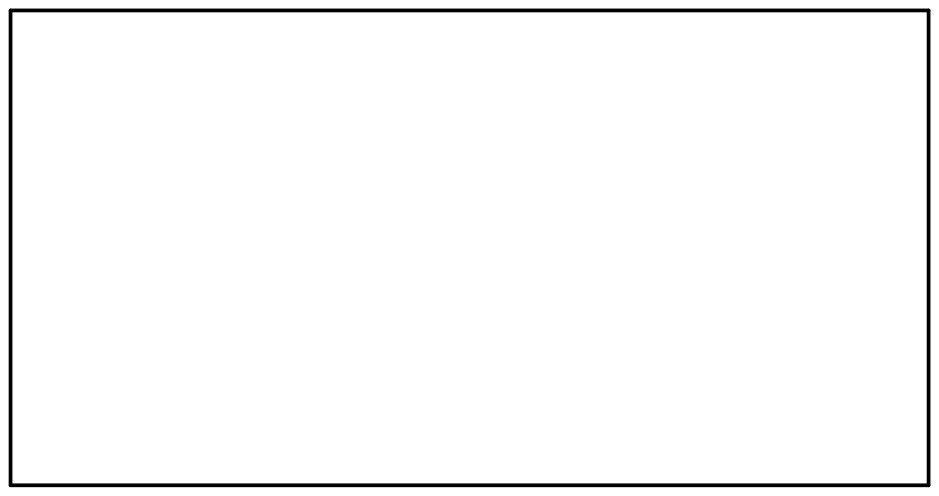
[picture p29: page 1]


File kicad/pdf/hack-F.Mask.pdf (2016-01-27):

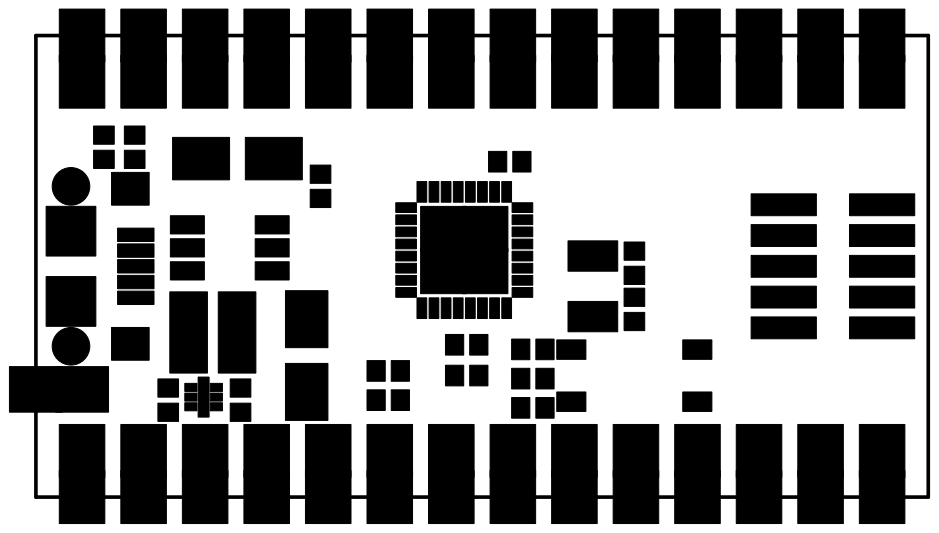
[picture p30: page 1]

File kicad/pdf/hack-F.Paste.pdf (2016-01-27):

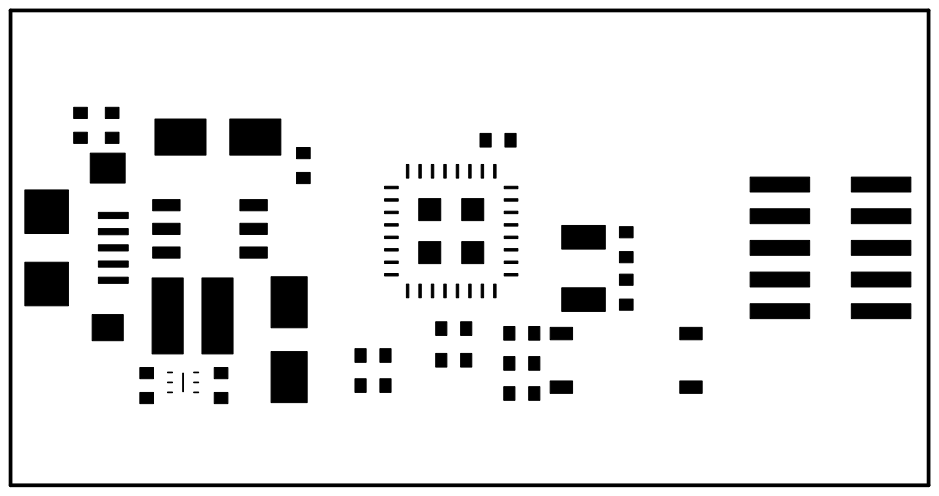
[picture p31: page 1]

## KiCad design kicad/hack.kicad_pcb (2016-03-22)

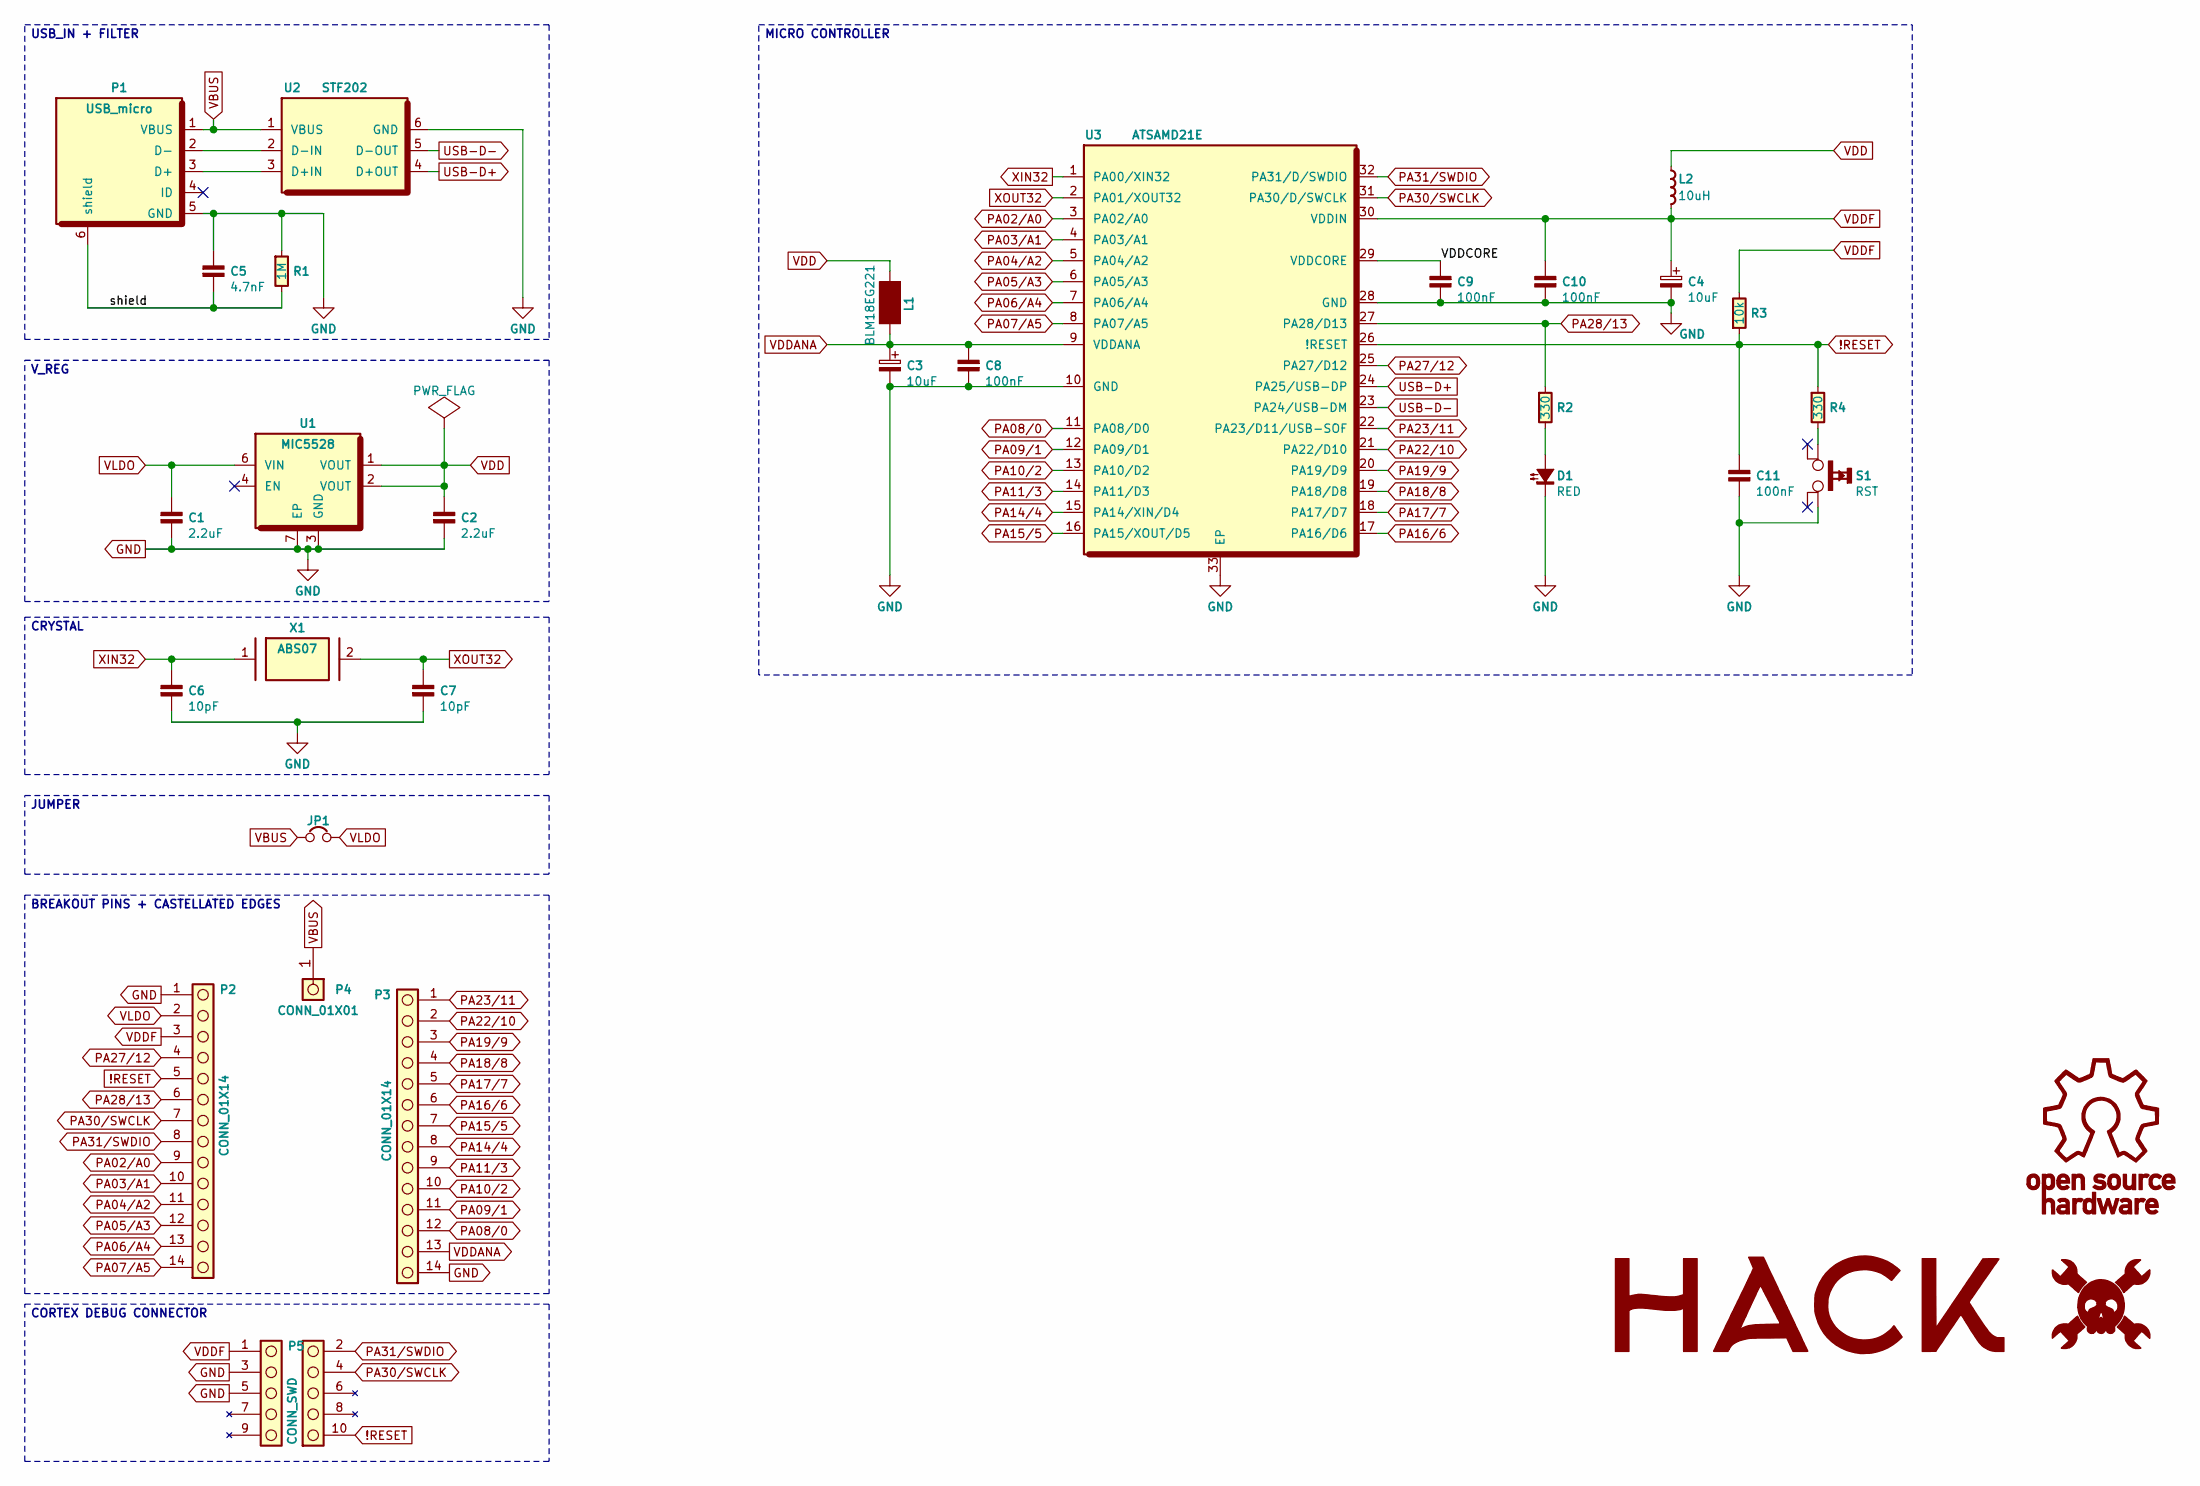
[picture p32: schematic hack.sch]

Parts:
C1, C2: 2.2uF; C_0603
C3, C4: 10uF; CAP_ELEC_SMD_3x5mm
C5: 4.7nF; C_0603
C6, C7: 10pF; C_0603
C8, C9, C10, C11: 100nF; C_0603
D1: RED; LED_0603
JP1: Jumper_NO_Small; SMD_Jumper
L1: BLM18EG221; L_0603
L2: 10uH; ELLVFG
LOGO1: OSHW; OSHW-LOGO
LOGO2: HACKADAY; HACKADAY-LOGO
LOGO3: HACK; HACK-LOGO
P1: USB_micro; ST-USB-001G
P2, P3: CONN_01X14; Pin_Castellated_1x14
P4: CONN_01X01; Pin_Castellated_1x01
P5: CONN_SWD; Cortex_Debug_Connector_50mils
R1: 1M; R_0603
R2, R4: 330; R_0603
R3: 10k; R_0603
S1: RST; SPST-PTS_810
U1: MIC5528; DFN-6-1EP_1.2x1.2mm_Pitch0.4mm
U2: STF202; TSOP-6
U3: ATSAMD21E; QFN-32-1EP_5x5mm_Pitch0.5mm
X1: ABS07; xtal_3.2x1.5mm

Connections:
!RESET: C11.1, P2.5, P5.10 (nRESET), R3.1, R4.1, U3.26 (!RESET)
/VDDCORE: C9.1, U3.29 (VDDCORE)
/shield: C5.2, P1.6 (shield), R1.2
GND: C1.2, C2.2, C3.2, C4.2, C5.1, C6.2, C7.2, C8.2, C9.2, C10.2, C11.2, D1.2 (K), P1.5 (GND), P2.1, P3.14, P5.3 (GND), P5.5 (GND), R1.1, S1.1, U1.3 (GND), U1.7 (EP), U2.6 (GND), U3.10 (GND), U3.28 (GND), U3.33 (EP)
unnamed: D1.1 (A), R2.2
unnamed: P1.2 (D-), U2.2 (D-IN)
unnamed: P1.3 (D+), U2.3 (D+IN)
unnamed: R4.2, S1.3
PA02/A0: P2.9, U3.3 (PA02/A0)
PA03/A1: P2.10, U3.4 (PA03/A1)
PA04/A2: P2.11, U3.5 (PA04/A2)
PA05/A3: P2.12, U3.6 (PA05/A3)
PA06/A4: P2.13, U3.7 (PA06/A4)
PA07/A5: P2.14, U3.8 (PA07/A5)
PA08/0: P3.12, U3.11 (PA08/D0)
PA09/1: P3.11, U3.12 (PA09/D1)
PA10/2: P3.10, U3.13 (PA10/D2)
PA11/3: P3.9, U3.14 (PA11/D3)
PA14/4: P3.8, U3.15 (PA14/XIN/D4)
PA15/5: P3.7, U3.16 (PA15/XOUT/D5)
PA16/6: P3.6, U3.17 (PA16/D6)
PA17/7: P3.5, U3.18 (PA17/D7)
PA18/8: P3.4, U3.19 (PA18/D8)
PA19/9: P3.3, U3.20 (PA19/D9)
PA22/10: P3.2, U3.21 (PA22/D10)
PA23/11: P3.1, U3.22 (PA23/D11/USB-SOF)
PA27/12: P2.4, U3.25 (PA27/D12)
PA28/13: P2.6, R2.1, U3.27 (PA28/D13)
PA30/SWCLK: P2.7, P5.4 (SWDCLK), U3.31 (PA30/D/SWCLK)
PA31/SWDIO: P2.8, P5.2 (SWDIO), U3.32 (PA31/D/SWDIO)
USB-D+: U2.4 (D+OUT), U3.24 (PA25/USB-DP)
USB-D-: U2.5 (D-OUT), U3.23 (PA24/USB-DM)
VBUS: JP1.1, P1.1 (VBUS), P4.1, U2.1 (VBUS)
VDD: C2.1, L1.1, L2.1, U1.1 (VOUT), U1.2 (VOUT)
VDDANA: C3.1, C8.1, L1.2, P3.13, U3.9 (VDDANA)
VDDF: C4.1, C10.1, L2.2, P2.3, P5.1 (VTref), R3.2, U3.30 (VDDIN)
VLDO: C1.1, JP1.2, P2.2, U1.6 (VIN)
XIN32: C6.1, U3.1 (PA00/XIN32), X1.1
XOUT32: C7.1, U3.2 (PA01/XOUT32), X1.2

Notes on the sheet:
USB_IN + FILTER
V_REG
CRYSTAL
JUMPER
BREAKOUT PINS + CASTELLATED EDGES
MICRO CONTROLLER
CORTEX DEBUG CONNECTOR

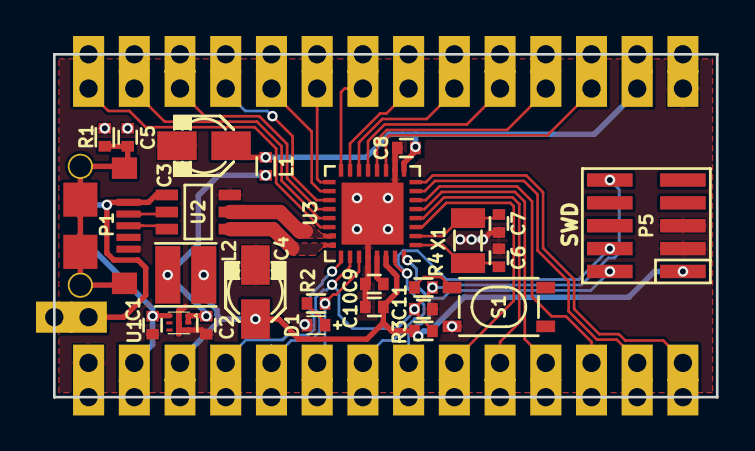
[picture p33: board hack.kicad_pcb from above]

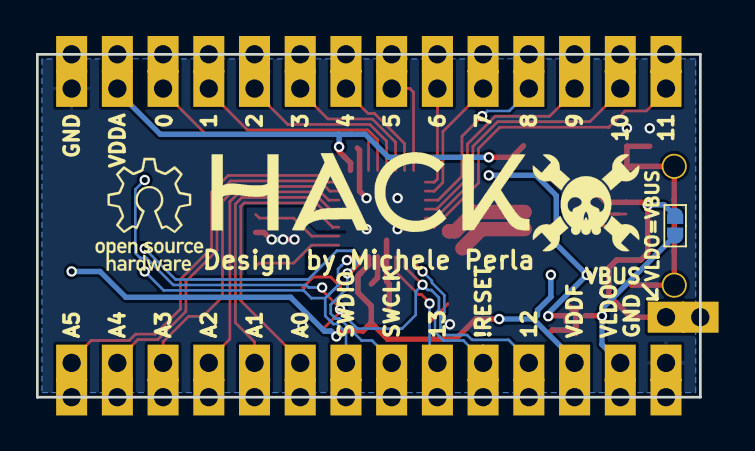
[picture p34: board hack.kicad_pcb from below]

Board: 2 copper layers, 36.8 x 19.1 mm, 32 parts (6 on the bottom side), 39 nets.

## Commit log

2015-10-05 Second commit
    [hack.brd, hack.sch]
2015-10-08 Finishing layout, added PCB antenna
    [hack.brd, hack.sch]
2015-10-12 Third commit
    Changed cutout of PCB so that one side hosts the antenna; moved part of
    the header to the right side (use a female receptacle instead of a male
    header to retain breadboard usability)
    [hack.brd, hack.sch]
2015-10-12 Added temp EAGLE CAD files to .gitignore
2015-10-12 Added impedance controlled microstrips
    Added impedance controlled microstrips (diff. impedance of 100 Ohms from
    chip to balun, single ended impedance of 50 Ohms from balun to antenna)
    [hack.brd, hack.sch]
2015-10-13 1st revision board is done
    [hack.brd, hack.sch]
2015-10-14 3D model added
    It's missing the balun and the 32.768 KHz crystal models only
    [hack.brd, hack.sch]
2015-12-21 Migrating project to KiCAD
    [hack.brd, hack.kicad_pcb, hack.sch]
2015-12-23 Final components placement almost done
    During this phase I checked if everything could fit in the board. It
    didn't, so I found a replacement LDO (in a small 1.2x1.2mm DFN package)
    that needs 2x0603 ceramic caps rather than two clunky electros (more
    free space then) and I finally changed the D21E package to QFN as well,
    now everything seems to fit quite well.
    [hack.kicad_pcb, hack.sch]
2015-12-24 Layout 99,9% finished
    Nets 100% routed, need to double check if copper pours are all connected
    to ground; added fiducials on board (for pick-n-place machines), I only
    need to find a good spot for them
    [hack.kicad_pcb, hack.sch]
2015-12-28 Cleaning up before test run
    Removed obsolete Eagle CAD files, added OSHW/Hackaday logos on schematic
    and silkscreen, removed ground connections for pins 2-3 of 32.768 KHz
    XTAL, removed traces under USB data lines, moving analog lines around
    (not beneath) XTAL (w.i.p.), moved components names on silkscreen to be
    readable, set fiducials in position, fixed SPST SMD package
    [hack.brd, hack.kicad_pcb, hack.sch]
2015-12-29 Layout 100% completed, cosmetics not yet
    [hack.kicad_pcb, hack.sch]
2016-01-04 Finished silkscreen cosmetics, added gerbers
    [hack-B_Cu.gbr, hack-B_Mask.gbr, hack-B_SilkS.gbr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]
2016-01-05 Added castellated pins
    [hack-B_Cu.gbr, hack-B_Mask.gbr, hack-B_SilkS.gbr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]
2016-01-05 Fixed gerbers (silkcreen issue with one pin)
    [hack-B_Cu.gbr, hack-B_Mask.gbr, hack-B_SilkS.gbr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]
2016-01-05 Changed USB connector package, revised layout
    [hack.kicad_pcb, hack.sch]
2016-01-05 Updated GERBER files, removed DRC errors in PCB
    [hack-B_Cu.gbr, hack-B_Mask.gbr, hack-B_SilkS.gbr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]
2016-01-05 fresh PDF and Gerbers in separate folders. Step/VRML files ready for 3D render
    [Cap_SMD_0603.step, Cap_SMD_el_4x5.step, Ind_SMD_0603.step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]
2016-01-06 FreeCAD 3D render in Fabricate dir, moved gerber dir nested under kicad
    [Cap_SMD_0603.step, Cap_SMD_el_3x5.step, Cap_SMD_el_4x5.step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]
2016-01-06 Added datasheets, manufacturer numbers field for every component
    [hack.sch, hack.xlsx]
2016-01-06 Updated KiCost BOM file w manf# field
    [hack.xlsx]
2016-01-06 Added pin header datasheet+manf# (15 pins instead of 13 because 15 is cheaper)
    [hack.sch]
2016-01-07 added 3d model for ELL-VFG and some other minor edits
    [Ind_ell_vfg.step, hack.FCStd, hack.kicad_pcb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]
2016-01-07 Added Seeedstudio costs for some components in schematic, changed 2.2uF manf# field to real manufacturer number instead of Seeedstudio SKU
    [hack.sch]
2016-01-07 Updated Seeedstudio cost information
    [hack.sch]
2016-01-07 Fixed KiCost BOM issue, updated BOM
    [hack.sch, hack.xlsx]
2016-01-07 Updated BOM, added sheet fixed for 20 boards
    Usefult for test run purposes
    [hack.xlsx]
2016-01-07 Updated BOM
    [hack.xlsx]
2016-01-08 Added secondary USB connector footprint
    Previous one is only available from Seeedstudio, this one is from FCI
    and available from all distributors
    [hack.kicad_pcb]
2016-01-08 Changed LED, headers, USBmicro, XTAL manf#
    These parts are readily available from all distributors, previous ones
    were only sold by Seeed
    [hack.sch]
2016-01-08 Updated BOMs
    One contains normally available parts numbers (hack-Digi-BOM), the other
    contains mostly Seeedstudio-sourced parts numbers (hack-Seeed-BOM)
    [hack-Digi-BOM.xlsx, hack-Seeed-BOM.xlsx]
2016-01-18 Optimized footprints, freed some PCB real estate
    [hack.kicad_pcb]
2016-01-18 Updated fabrication files
    [hack-B.Cu.gbl, hack-B.Mask.gbs, hack-B.SilkS.gbo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]
2016-01-18 Updated BOM (re-runned KiCost to check today's price)
    [hack-Digi-BOM.xlsx]
2016-01-18 Fixed gerbers (outline was in all layers)
    [hack.kicad_pcb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]
2016-01-18 Fixed PCB (not connected LED ground), updated fab files accordingly
    [hack.kicad_pcb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]
2016-01-18 Updated pcb+gerber (via was still missing from D1 to GND)
    [hack-B.Cu.gbl, hack-B.Mask.gbs, hack-B.SilkS.gbo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]
2016-01-18 fresh gerber and seeed BoM for ready for prototype
    [hack-Seeed-BOM.xlsx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]
2016-01-19 added Freecad 3d model for ELL-VFG inductor
    [Ind_ell_vfg.fcstd]
2016-01-20 Added VBUS pin, GND pin near VDDANA
    [hack-B.Cu.gbl, hack-B.Mask.gbs, hack-B.Paste.gbp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]
2016-01-21 Reducing board size (w.i.p.)
    [hack.kicad_pcb, hack.sch]
2016-01-22 Reduced overall board size
    [hack-B.Cu.gbl, hack-B.Mask.gbs, hack-B.Paste.gbp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]
2016-01-22 Fixed footprints refereneces on top silkscreen
    [hack-B.Cu.gbl, hack-B.Mask.gbs, hack-B.Paste.gbp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]
2016-01-22 Added back gerber files zip
2016-01-25 Form factor is PDIP-24 now, ready to fab
    HACK now fits a PDIP-24 package (its solderable thru-hole headers
    spacing is now 0.6"); being longer there's some space on the top side,
    so it now features a convenient Cortex SWD Connector, a 2x5 male pin
    header with 50 mils spacing in SMD package.
    [hack-B.Cu.gbl, hack-B.Mask.gbs, hack-B.Paste.gbp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]
2016-01-28 fresh 3D model and graphics
    [PCB Technology Requirement Format V1 for HACK.xlsx, SW_tact_6x3.step, hack.FCStd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]
2016-03-22 new 3D models from Maurice with open source license
    [10118193-0001LF.step, Cap_SMD_0603.step, Cap_SMD_el_3x5.step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]

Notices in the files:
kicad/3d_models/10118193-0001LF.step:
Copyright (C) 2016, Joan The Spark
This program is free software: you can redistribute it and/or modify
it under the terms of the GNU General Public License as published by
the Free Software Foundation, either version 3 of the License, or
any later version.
